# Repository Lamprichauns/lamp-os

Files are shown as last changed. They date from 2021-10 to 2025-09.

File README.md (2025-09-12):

# LampOS

A platform for retrofitting traditional desk lamps with programmable LED controllers to build unique lighted art structures. Using standardized and user friendly hardware based on the ubiquitous ESP32, Neopixels and common sensors, this project seeks to simplify the job of building curious and surreal LED projects for the community to enjoy.

## Lamp Personality & Behaviours

The vision for the lamps is that they remain mostly still and static, as a contrast to the plethora of sound reactive and blinky light art out there. The brightness of the lamps and the colorful glowing base draws attention to the juxtaposition of an ordinary household object in extraordinary places.

Within this vision there is room for the lamps to have personality, shown through subtle behaviour based on things like time, randomness, sensor data, presence/absence of other lamps, etc.

With these sorts of subtle changes, people may begin to realize things are not as static as they seem, creating a somewhat complex puzzle for people to solve and talk about.

## Selecting a lamp to convert

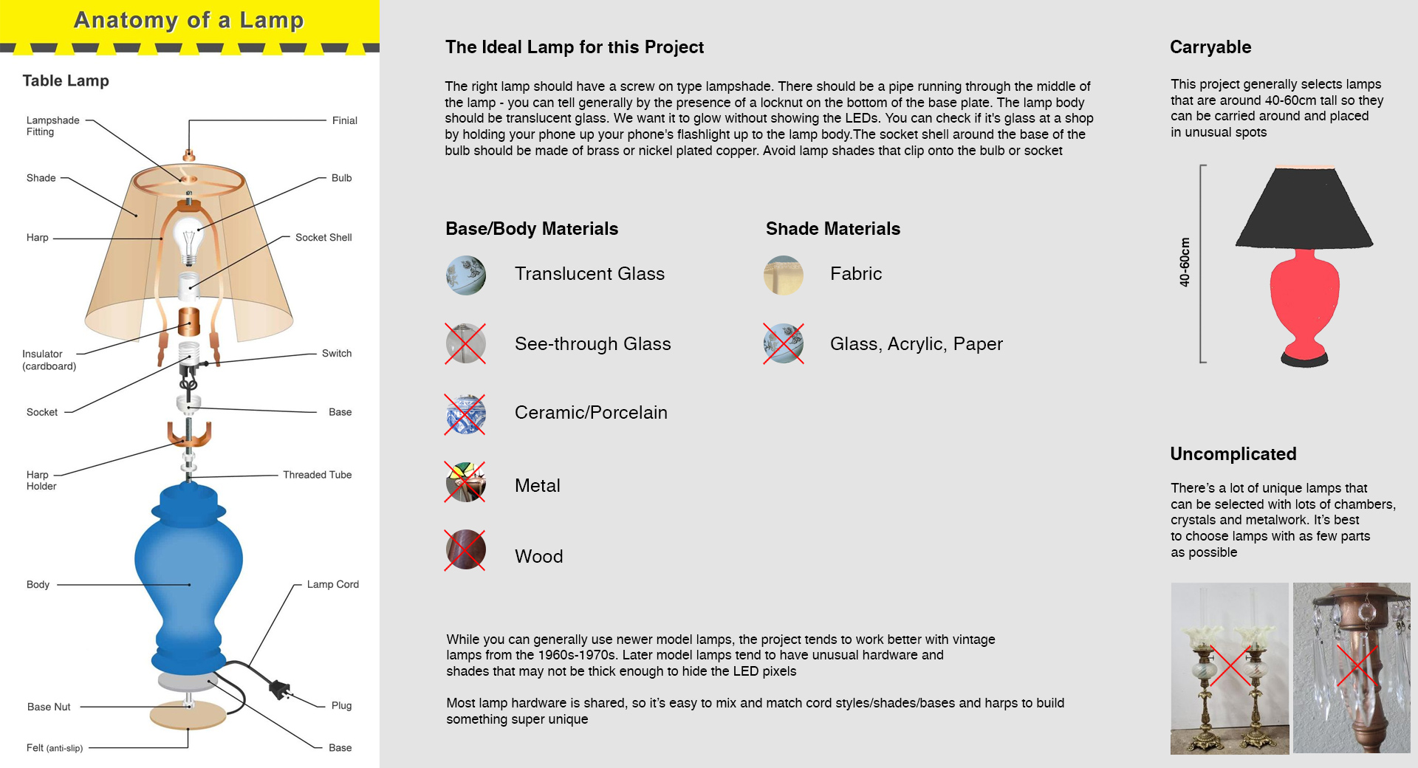
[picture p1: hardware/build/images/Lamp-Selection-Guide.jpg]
Preferred lamp guidelines


## Lamp Hardware Requirements

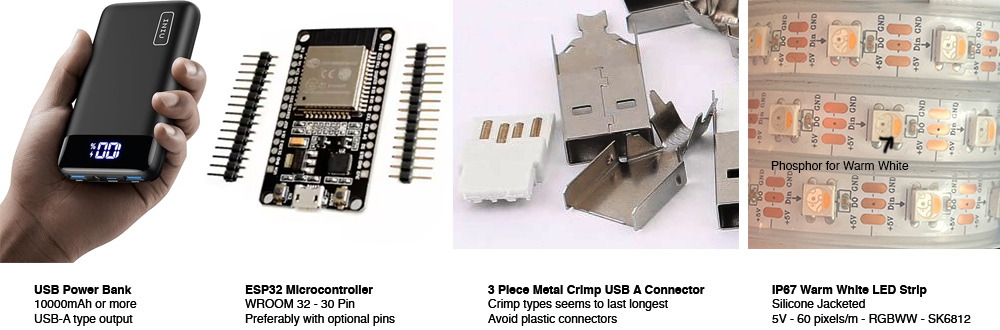
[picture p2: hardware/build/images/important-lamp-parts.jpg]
Main Lamp Components


This software is intended for the ESP32 platform. Our preferred dev board is an ESP32-WROOM32 30 Pin board variant measuring no wider than 28mm with a chip antenna. Unsoldered/unwelded pins are preferred if possible. This space requirement is so the board can fit comfortably into a standard lamp socket. The boards can be had easily from Amazon and AliExpress for $5-10. The model we use has this pinout <https://lastminuteengineers.com/esp32-pinout-reference/>

The USB connector is a USB type A metal shell crimp on connector. These tend to be the most robust.

By default, a lamp will use about 80 LEDs. The limiting factor at the moment is current draw. generally over 100 LEDs you may have stability issues with a conventional USB source. We recommend purchasing LEDs strips with the following specs:

- Around 2m in length
- SK6812 chipset
- IP67 waterproof
- 5VDC
- RGBWW (warm white) LED Strips
- Spacing of 60 LEDs/m

A 10000mAh battery pack with USB will run this device portably for around 7 hours

You'll also need some basic workshop tools, heat shrink, wire connectors, a soldering iron and a way to print the plastic bulb

There's a handy [build guide with images here](hardware/build/README.md)

## Lamp OS

More details about Lamp OS and other supporting tools can be found in the [software](software/) folder

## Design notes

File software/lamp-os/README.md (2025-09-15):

# Lamp OS

---
This is the main software aboard the lamps. It's a small LED driver focused on slow animations and social behaviors

## Contributing

This project runs on pioarduino, a VS Code plugin for all platforms. Pioarduino can be found in the VS Code marketplace

## Prerequisites

You'll need the following software packages

* <https://www.python.org/downloads/> (At least version 3.10)
* Python 3.10+ added to your path
* <https://code.visualstudio.com/>
* pioarduino (accessed from VS Code's extensions tab)

## Opening the project

 Clone this branch to a local folder. Find the folder in the Pioarduino tab on the sidebar of VS Code

## Setting up your editor

We're using Google's code style for this application. All lamp specific code will be added to a flat `lamp` namespace.

You can auto format your code by changing the Vscode settings (ctrl + shift + p > Open user settings (json)):

```json
    "cSpell.diagnosticLevel": "Hint",
    "editor.formatOnSave": true,
    "editor.formatOnSaveMode": "file",
    "C_Cpp.clang_format_fallbackStyle": "{ BasedOnStyle: Google, IndentWidth: 2, ColumnLimit: 0}"
```

## Flashing

 Currently the flash process is a few steps:

 If you've got a completely new board, it's prudent to run erase flash to completely clear your device:

* Pioarduino in the VSCode sidebar -> Project Tasks -> Platform -> Erase Flash

To push the web app in the data dir, you can run

* Pioarduino in the VSCode sidebar -> Project Tasks -> Platform -> build filesystem image
* Pioarduino in the VSCode sidebar -> Project Tasks -> Platform -> upload filesystem image

To upload the factory firmware image:

* Pioarduino in the VSCode sidebar -> Project Tasks -> General -> upload

 Note that depending on the board, you may need to hold the boot button in order to flash the board.

## Updating the web app for development

Plug your lamp board into a usb port

In VSCode, navigate to `Pioarduino > Quick Access > Miscellaneous > pioarduino core CLI`

This will bring up a window in the correct environment to upload

```bash
cd ../lamp-ui
npm ci
npm run build:upload
```

This process will build a new .spiffs partition and replace it onboard your esp32.

## Distribution

While you can program boards through the IDE, Lamp OS intends to be deployed on the web so anyone can format and maintain their own firmware

## OTA Updating

Join your lamp's wifi and navigate to <http://lamp.local/update> and update the following two files in pairs:

Lamp's main firmware:

* file: firmware.bin
* OTA Mode: Firmware

Lamp's mobile UI:

* file: spiffs.bin
* OTA Mode: LittleFS/Spiffs

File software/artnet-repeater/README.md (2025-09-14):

# ArtNet Repeater

---
This is an unstable branch for development of an artnet repeater to control multiple lamps from one unicast ArtNet address with support for a single universe. This project uses wifi on an Seeed Xiao ESP32C6 board with a remote antenna. There will be more packet loss on chip antennas and more noticeable lag in animations as a result

## Contributing

This project runs on pioarduino, a VS Code plugin for all platforms. Pioarduino can be found in the VS Code marketplace.

## Prerequisites

You'll need the following software packages

* <https://www.python.org/downloads/> (At least version 3.10)
* Python 3.10+ added to your path
* <https://code.visualstudio.com/>
* pioarduino (accessed from VS Code's extensions tab)

## Opening the project

 Clone this branch to a local folder. Find the folder in the Pioarduino tab on the sidebar of VS Code

## Setting up your editor

We're using google's code style for this application

You can auto format your code by changing the vscode settings (ctrl + shift + p > Open user settings (json)):

```json
    "cSpell.diagnosticLevel": "Hint",
    "editor.formatOnSave": true,
    "editor.formatOnSaveMode": "file",
    "C_Cpp.vcFormat.newLine.beforeOpenBrace.namespace": "sameLine",
    "C_Cpp.vcFormat.newLine.beforeOpenBrace.type": "sameLine",
    "C_Cpp.vcFormat.newLine.scopeBracesOnSeparateLines": false,
    "C_Cpp.vcFormat.newLine.beforeOpenBrace.block": "sameLine",
    "C_Cpp.vcFormat.newLine.beforeOpenBrace.function": "sameLine",
    "C_Cpp.clang_format_fallbackStyle": "{ BasedOnStyle: Google, IndentWidth: 2 }"
```

## Project Setup

Copy the file `secrets_sample.hpp` to `secrets.hpp` and add any WiFi and stage name credentials you want. Otherwise leave it blank

Some restrictions:

* stage name must be under 12 chars and lower case
* wifi ssid and password must be under 24 chars combined

## Flashing

Find and run the following task once Pioarduino has finished setup:

* Pioarduino in the VSCode sidebar -> project tasks -> general -> upload

 Note that depending on the board, you may need to hold the boot button in order to flash the board.

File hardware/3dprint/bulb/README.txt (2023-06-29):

3d printed bulbs are designed to snap onto the original brass sockets that come
with each lamp. LEDs are wrapped around the upper part of the bulb and secured
with silicone and clear gorilla tape. The 3 LED wires use the hole in the
housing and should be sealed with silicone to prevent water from getting in

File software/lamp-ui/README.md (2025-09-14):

# Lamp OS Color Picker

A mobile-first Vue.js color picker component with hexww (hex + warm white) support. Built with Vue 3, TypeScript, and Vitest.

## Features

- **Hexww Support**: Supports 8-digit hex values with warm white component (e.g., `#FF0000FF`)
- **Mobile-First Design**: Responsive design that works great on mobile devices
- **Interactive Dialog**: Click-to-open color picker with sliders for RGBA and warm white
- **Real-time Updates**: Changes to sliders update the hex value in real-time
- **Background Shading**: Modal dialog with clickable overlay to close
- **TypeScript Support**: Fully typed with TypeScript
- **Comprehensive Testing**: Unit tests with Vitest

## Color Format

The color picker supports the hexww format:

- **Standard Hex**: 6-digit hex values (e.g., `#FF0000`)
- **Hexww**: 8-digit hex values with warm white component (e.g., `#FF0000FF`)

The format is: `#RRGGBBWW` where:

- `RR` = Red component (00-FF)
- `GG` = Green component (00-FF)
- `BB` = Blue component (00-FF)
- `WW` = Warm White component (00-FF)

## Installation

```bash
# Clone the repository
git clone <repository-url>
cd software/lamp-ui

# Install dependencies
npm ci

# Start development server
npm run dev

# Run tests
npm run test:unit

# Build for production
npm run build
```

## Usage

### Basic Usage

```vue
<template>
  <ColorPicker v-model="selectedColor" />
</template>

<script setup>
import { ref } from 'vue'
import ColorPicker from '@/components/ColorPicker.vue'

const selectedColor = ref('#FF0000FF')
</script>
```

### Component Props

| Prop | Type | Default | Description |
| --- | --- | --- | --- |
| `modelValue` | `string` | `''` | The hexww color value |

### Component Events

| Event | Payload  | Description |
| --- | --- | --- |
| `update:modelValue` | `string` | Emitted when the color value changes |

## Development

### Project Structure

```
src/
├── components/
│   ├── ColorPicker.vue          # Main color picker component
│   └── __tests__/
│       └── ColorPicker.test.ts  # Component tests
├── views/
│   └── HomeView.vue             # Demo page
├── App.vue                      # Root component
└── main.ts                      # Application entry point
```

### Running Tests

```bash
# Run all tests
npm run test:unit

# Run tests in watch mode
npm run test:unit -- --watch
```

### Building

```bash
# Build for production
npm run build

# Preview production build
npm run preview
```

### Uploading to your board

Plug your lamp board into a usb port

In VSCode, from the `lamp-os` project, navigate to `Pioarduino > Quick Access > Miscellaneous > pioarduino core CLI`

This will bring up a window in the correct environment to upload

```bash
cd ../lamp-ui
npm ci
npm run build:upload
```

This process will build a new .spiffs partition and replace it onboard your esp32.

## Features in Detail

### Color Picker Dialog

- **Color Preview**: Large preview of the selected color
- **Hex Input**: Direct hex value input with validation
- **RGBA Sliders**: Individual sliders for red, green, blue, and warm white
- **Real-time Updates**: All changes update the hex value immediately
- **Click Outside to Close**: Click the overlay or X button to close

### Mobile Responsiveness

- Optimized for touch interactions
- Responsive layout that adapts to screen size
- Touch-friendly sliders and buttons
- Proper viewport handling

### Accessibility

- Proper ARIA labels
- Keyboard navigation support
- Focus management
- Screen reader friendly

## Example Colors

The demo page includes several example colors:

- **Pure Red**: `#FF0000FF`
- **Pure Green**: `#00FF00FF`
- **Pure Blue**: `#0000FFFF`
- **Warm White**: `#000000FF`
- **Purple**: `#800080FF`
- **Orange**: `#FF8000FF`
- **Cyan**: `#00FFFFFF`
- **Magenta**: `#FF00FFFF`

## Technologies Used

- **Vue 3**: Progressive JavaScript framework
- **TypeScript**: Type-safe JavaScript
- **Vite**: Fast build tool and dev server
- **Vitest**: Unit testing framework
- **Vue Router**: Client-side routing
- **Pinia**: State management
- **ESLint**: Code linting
- **Prettier**: Code formatting

## Browser Support

- Chrome (latest)
- Firefox (latest)
- Safari (latest)
- Edge (latest)
- Mobile browsers (iOS Safari, Chrome Mobile)

## License

MIT License - see LICENSE file for details.

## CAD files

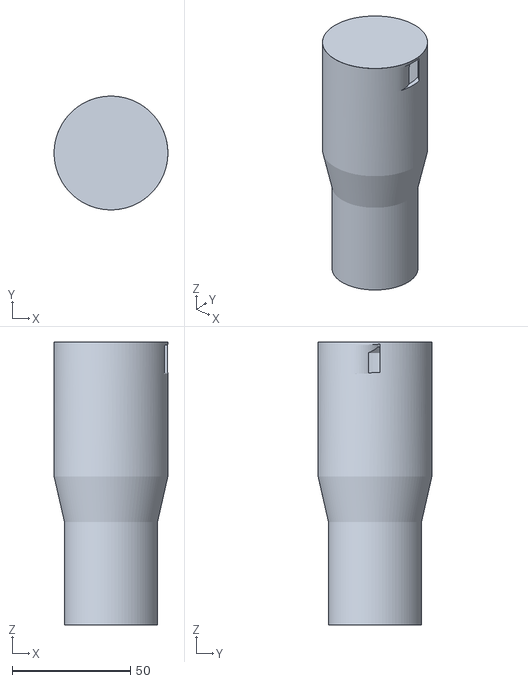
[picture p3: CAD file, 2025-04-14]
hardware/3dprint/bulb/bulb-with-guides.stl
48.2 x 48.1 x 119.8

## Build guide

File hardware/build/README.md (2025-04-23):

# Lamp Build Guide

As part of the process for making a lamp using Lamp OS, you'll need to convert the lamp to use a DC power source and add LEDs to the shade and base. This guide shows how we usually convert a lamp as an illustrated guide

## Prerequisites

To begin your build, you'll need a number of parts and tools ready to go

### Lamp Parts

More technical details of the parts you'll need to purchase can be found on the [main readme](../../README.md)

- A working lamp and shade
- USB Type A plug
- Some 4in cable ties
- An ESP32 board programmed with Lamp OS
- about 1.5m of 5V Neopixel style LED strip
- Some 24ga hookup wire in blue, red, black and yellow
- 3D printed bulb (optional)
- a pack of 24ga marettes (optional)
- a pack of lamp hardware (extra nuts/bolts/washers)
- a multimeter
- heat shrink tubing: 2, 3 and 10mm diameter
- a USB power bank (10000mAh or more)

### Tools

- hand drill and some assorted metal drill sizes
- wire cutters and strippers
- soldering iron
- some locking pliers/Visegrips for removing lamp hardware
- screwdrivers for lamp hardware (small phillips and slot head)
- 3d printer (optional)

## Parts of a Lamp

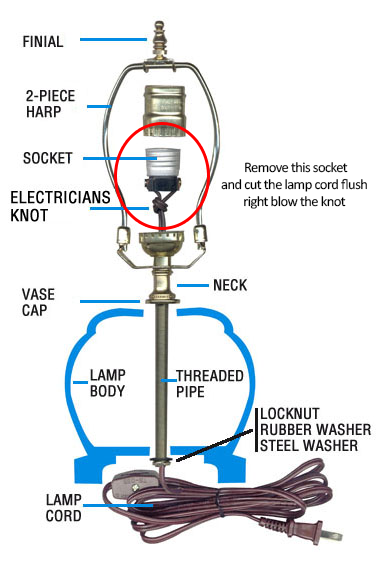
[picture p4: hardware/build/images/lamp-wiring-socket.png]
Basic lamp terminology


## Disassembly

To begin, you'll have to disassemble your lamp. The easiest way I've found to do this:

 1. remove the lampshade and light bulb
 2. unscrew the locking screw just below the bulb socket if it's there
 3. grab the base of the lamp and the socket and gently rotate them to loosen the entire internal assembly.
 4. The socket should completely unscrew from the rest of lamp hardware with enough turns
 5. clip the lamp cord at the socket side (shown in the figure above). Once the lamp cord is cut, you can pull it out of the lamp. It'll be reused in a later step
 6. take all the rest of the hardware apart and take some photos of the order that the parts go together
 7. put all the glass aside in a safe spot until final assembly

## Things to Build Ahead of Time

### Build a 3d printed shade bulb

Cut 35 LEDs from the strip and solder 3 wires - you may need to pull the LED strip out a little:

- black -> gnd
- yellow -> Din
- red -> +5V

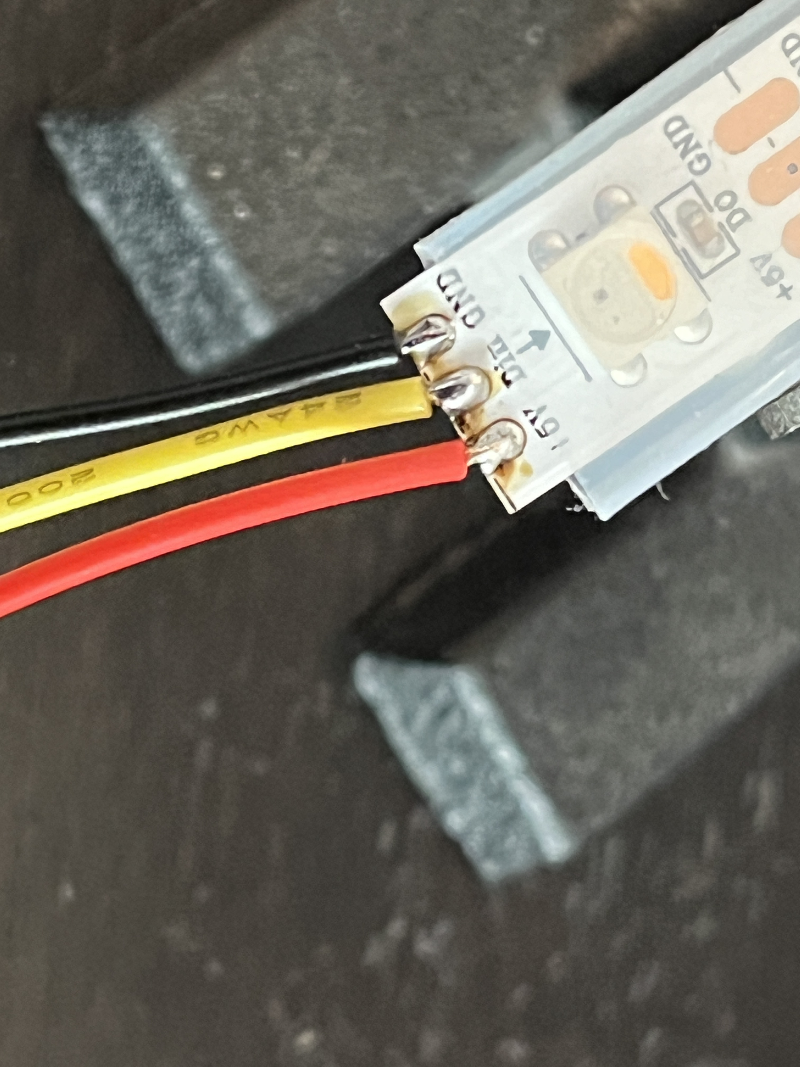
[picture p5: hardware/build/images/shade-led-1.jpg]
Soldering the Shade LEDs


Push the wires through the lower hole and clean up the 3d print so it's square as possible

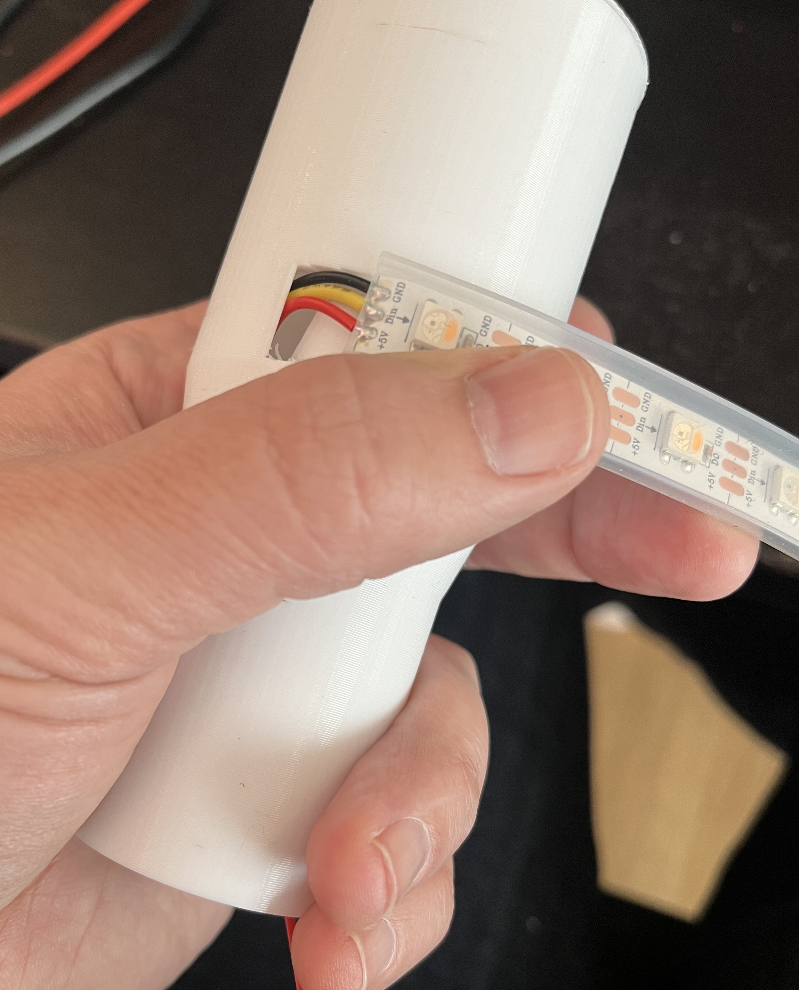
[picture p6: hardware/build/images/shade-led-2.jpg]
Push wires into the bulb


Wrap the LEDs around the bulb and tuck them into the top hole

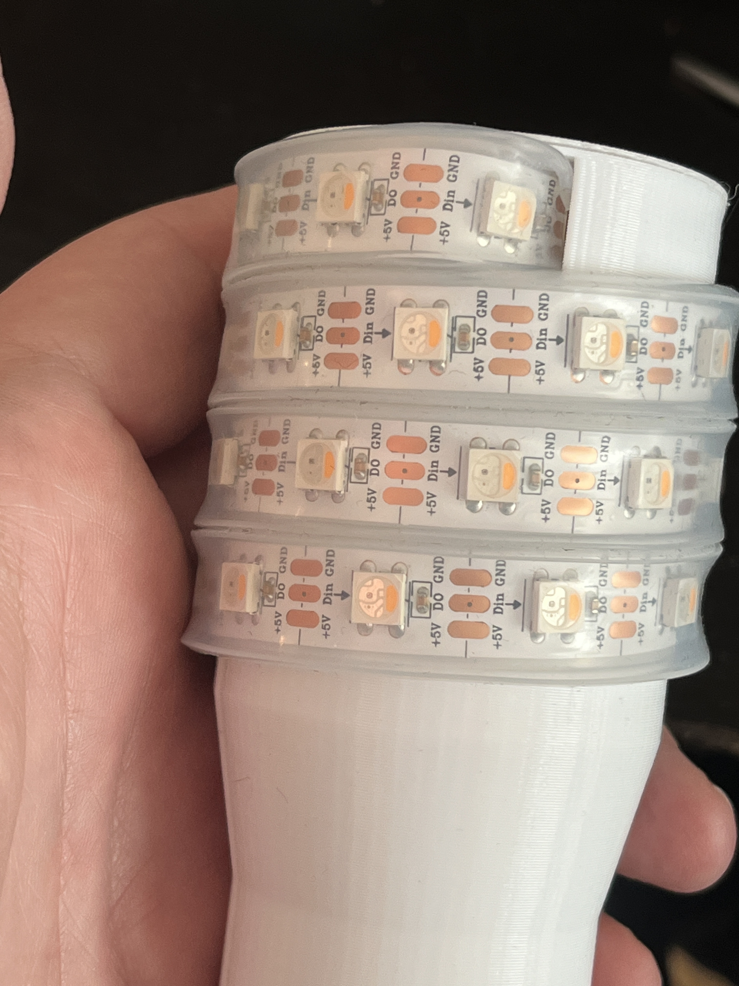
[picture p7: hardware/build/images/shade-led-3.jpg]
The bulb should hold the LEDs in place


Once the LEDs are in place, wrap them in clear tape to fasten them for good

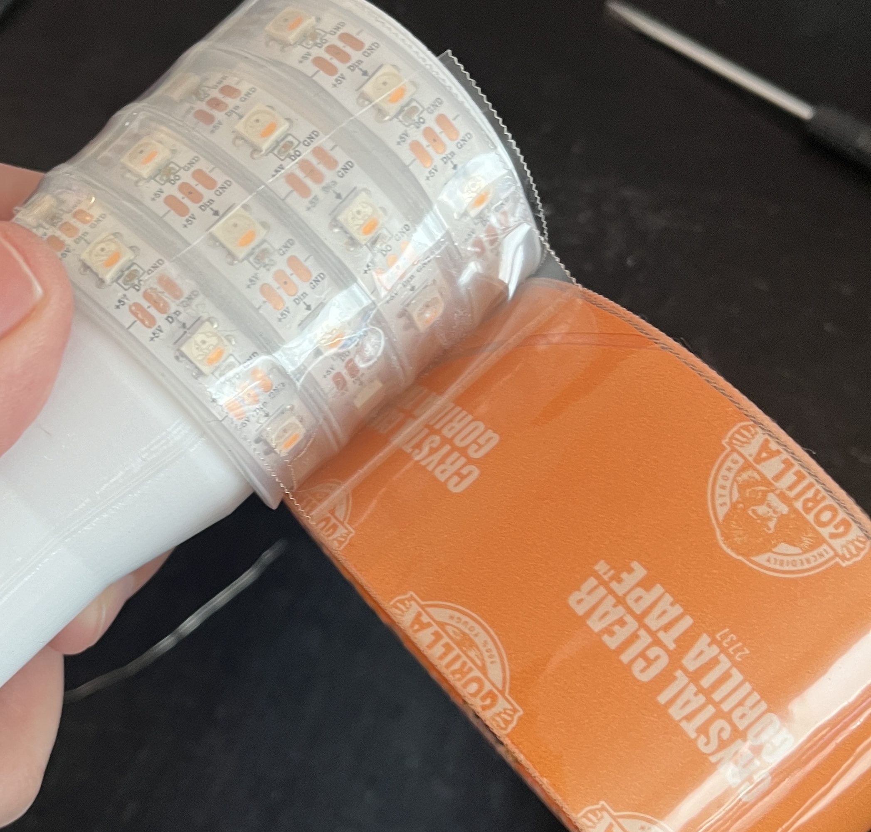
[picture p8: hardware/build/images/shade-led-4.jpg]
Wrap the LEDs with a couple layers of tape


### Build the PCB

Cut 4 wires around 6" each

- black -> GND
- red -> +5v/VIN
- yellow -> D12
- blue -> D14

You can zip tie these wires from any of the board's screw holes next to the D32 or EN pins.

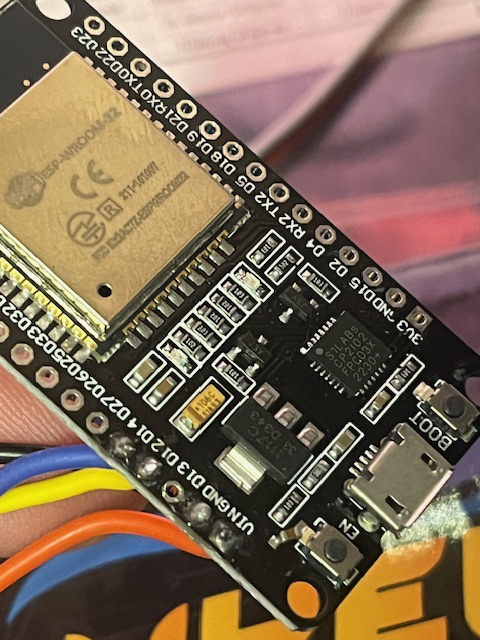
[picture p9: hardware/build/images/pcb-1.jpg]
PCB wiring

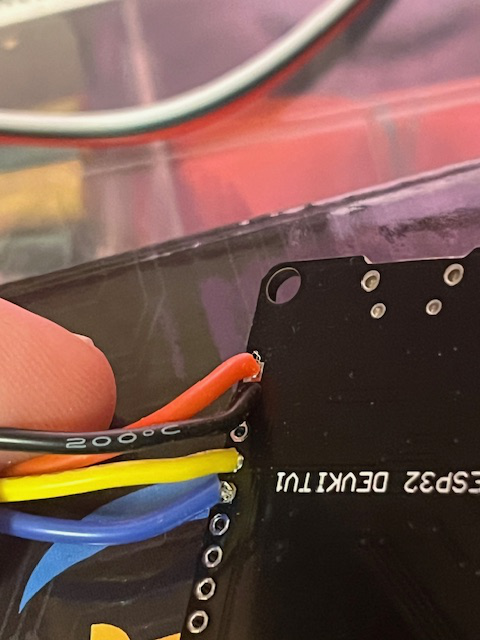
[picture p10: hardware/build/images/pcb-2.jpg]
PCB Wiring


## Assembly

Now the lamp is in pieces, we can begin converting it. The goal of the lamp conversion is to wire it up like this

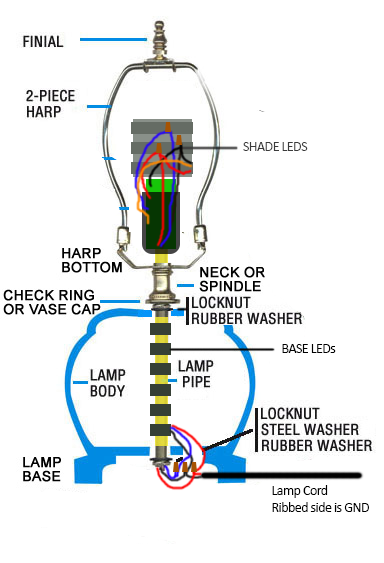
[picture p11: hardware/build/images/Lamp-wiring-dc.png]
Assembly plan


### Build Steps

Begin by drilling a few holes in the base. These holes should be as close to the lower locknut as possible.

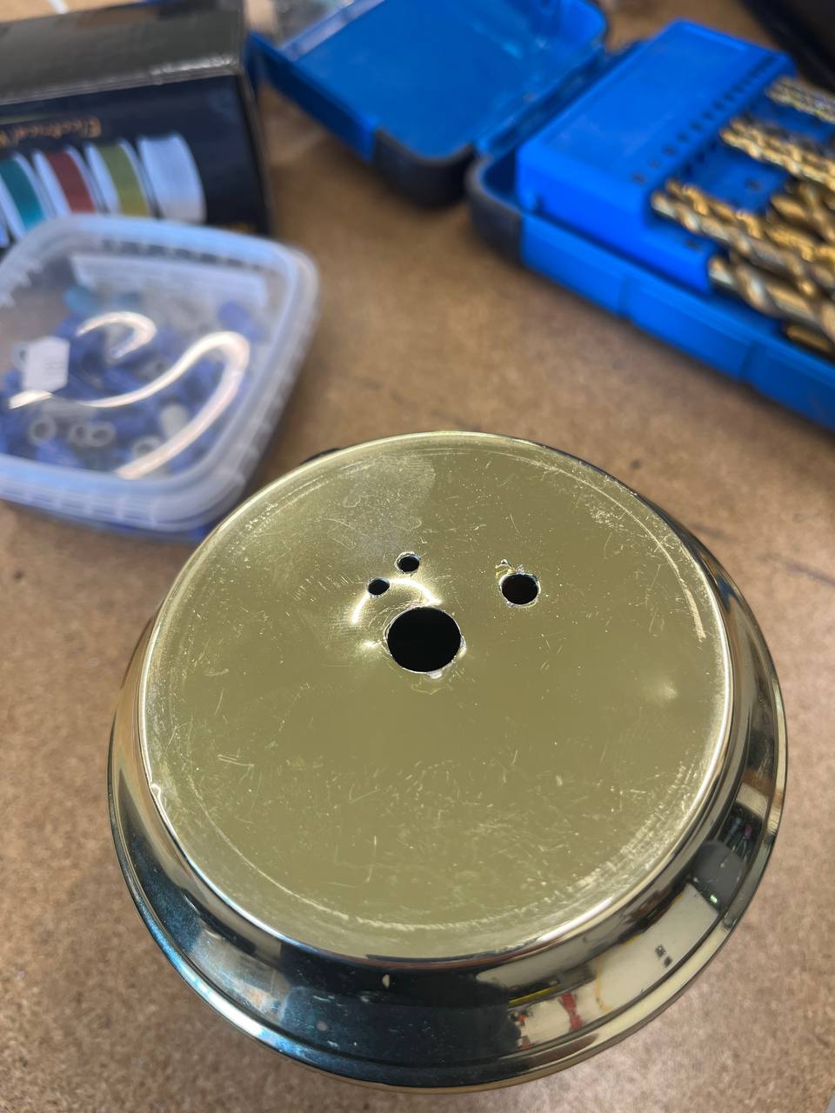
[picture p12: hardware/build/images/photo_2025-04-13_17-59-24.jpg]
Drilling the lamp base


Place a zip tie through the two smaller holes

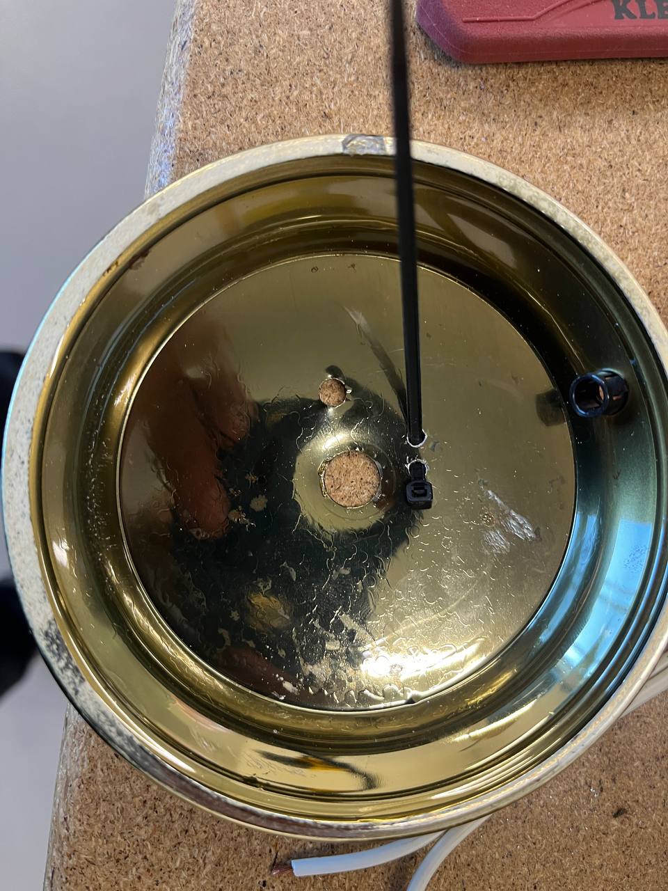
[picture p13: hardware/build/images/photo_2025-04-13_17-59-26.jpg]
Cord zip tie


Install the lamp pipe into the lamp base and install a top and bottom nut and bottom lock washer to secure the pipe in place. You may need to test fit the base glass a few times to ensure the pipe is in the right position

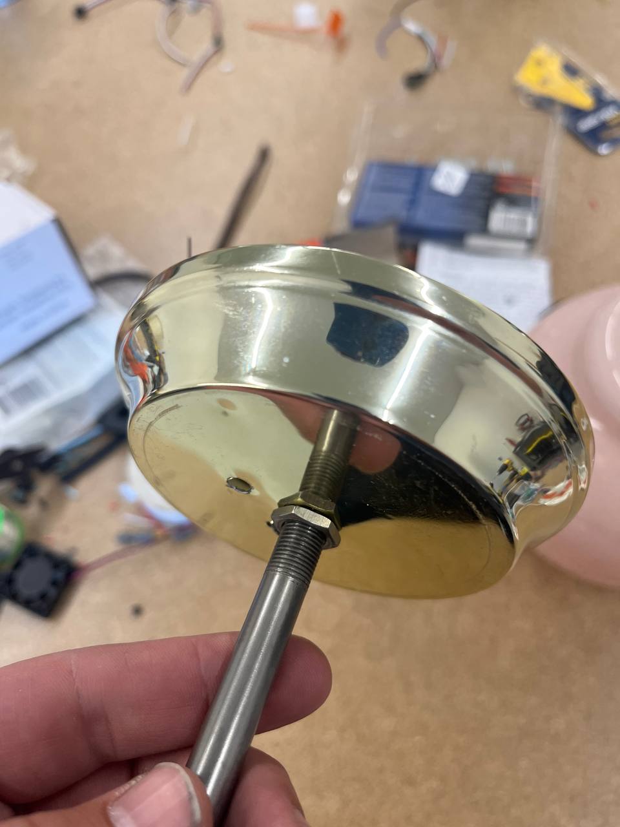
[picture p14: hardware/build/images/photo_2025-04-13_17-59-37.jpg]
Install the lamp pipe


Cut and remove the lamp cord from the socket

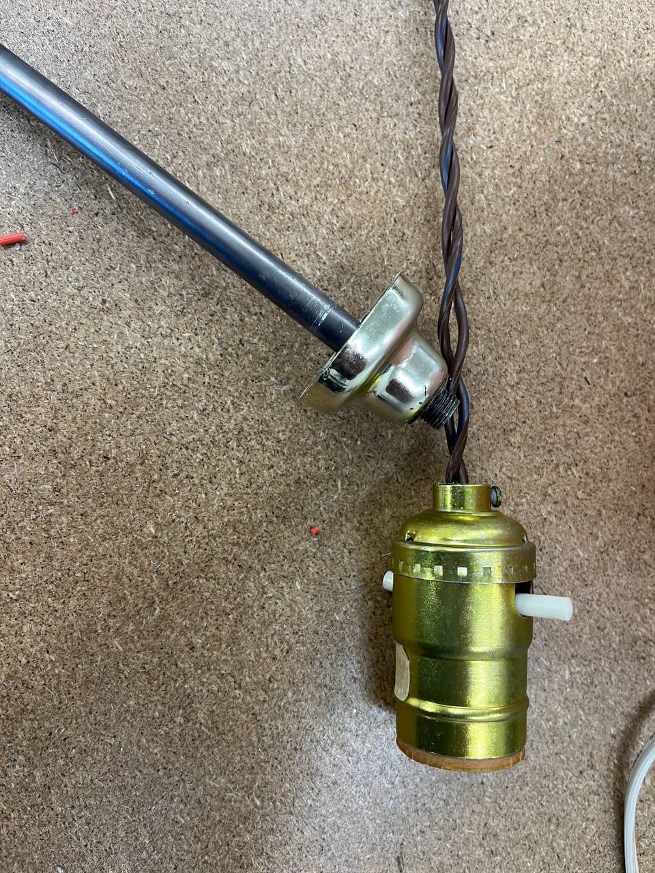
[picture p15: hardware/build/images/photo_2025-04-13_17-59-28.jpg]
Cut the lamp cord to prepare to convert it to USB


Strip the cable and solder it to the USB connector. The ribbed or striped side of the cable should be ground. Keep the solder as low profile as possible so it doesn't touch the metal on the top side of the connector. Close the connector by clipping in the top metal can part.

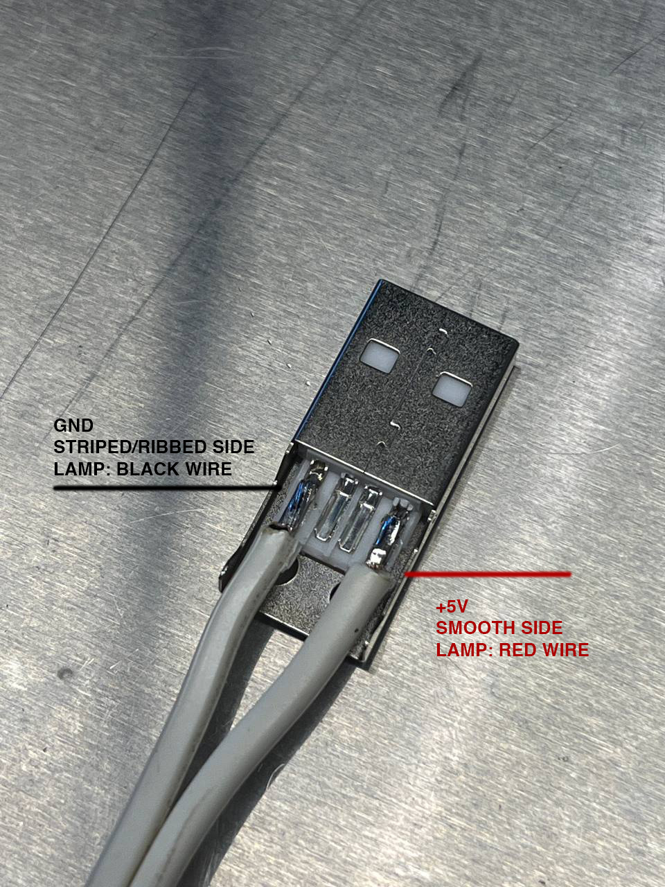
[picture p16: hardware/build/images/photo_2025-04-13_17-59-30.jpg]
Solder the USB connector


Double check your work on soldering the connector with a multimeter. Plug the connector into the battery. Connect the black lead to the ribbed/striped side of the lamp cord and the red lead to the other. In DC voltage mode, make sure 2-5V is coming out of the connector and in the right polarity

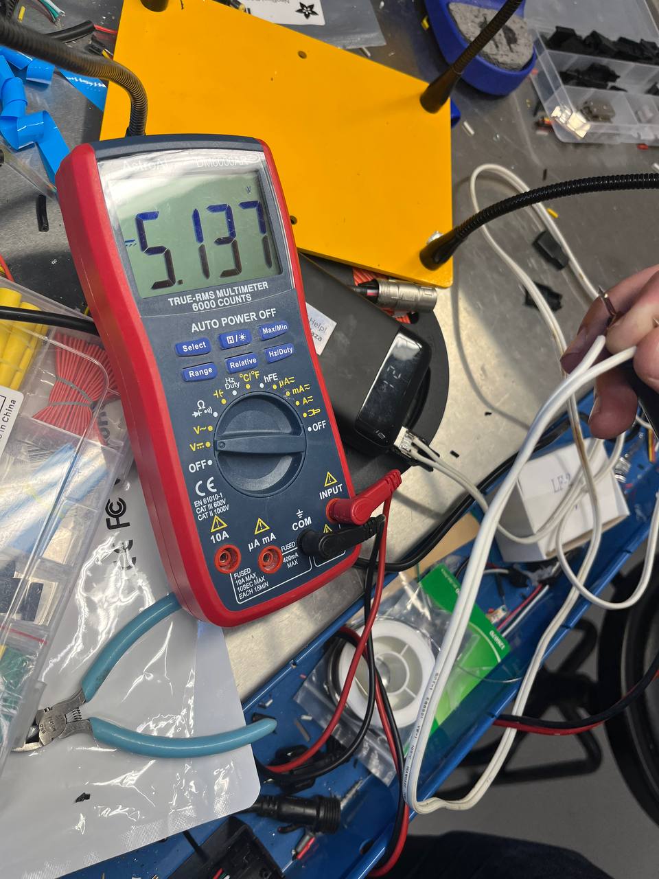
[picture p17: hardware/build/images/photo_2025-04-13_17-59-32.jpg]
Check for 2-5V on the other end of the lamp cord


Crimp the connector firmly to the wire using locking pliers or a crimp tool. Retest the connector once assembled and crimped. Apply heat shrink tubing (10mm diameter) up to about the midpoint of the usb connector and heat til it's tight. The lamp cord is now complete

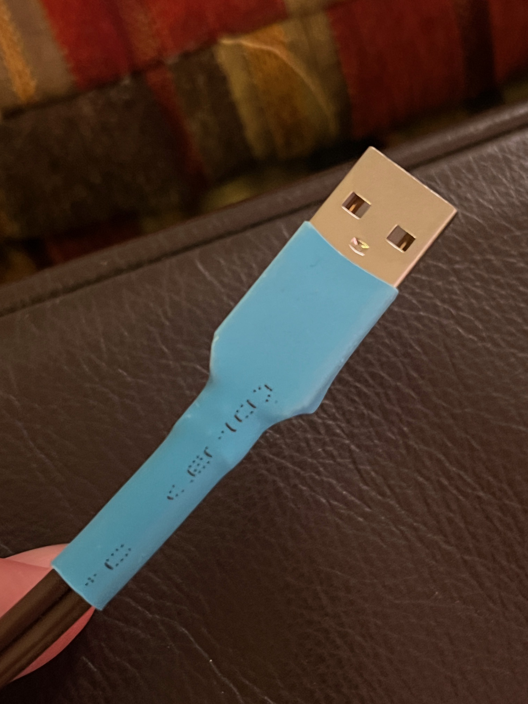
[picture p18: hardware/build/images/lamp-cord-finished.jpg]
finishing touches for the lamp plug


On the base LED strip, solder 3 wires:

- black -> gnd
- blue -> Din
- red -> +5V

And wrap it around the lamp pipe to the top of the base glass. It's generally about 30-40 LEDs

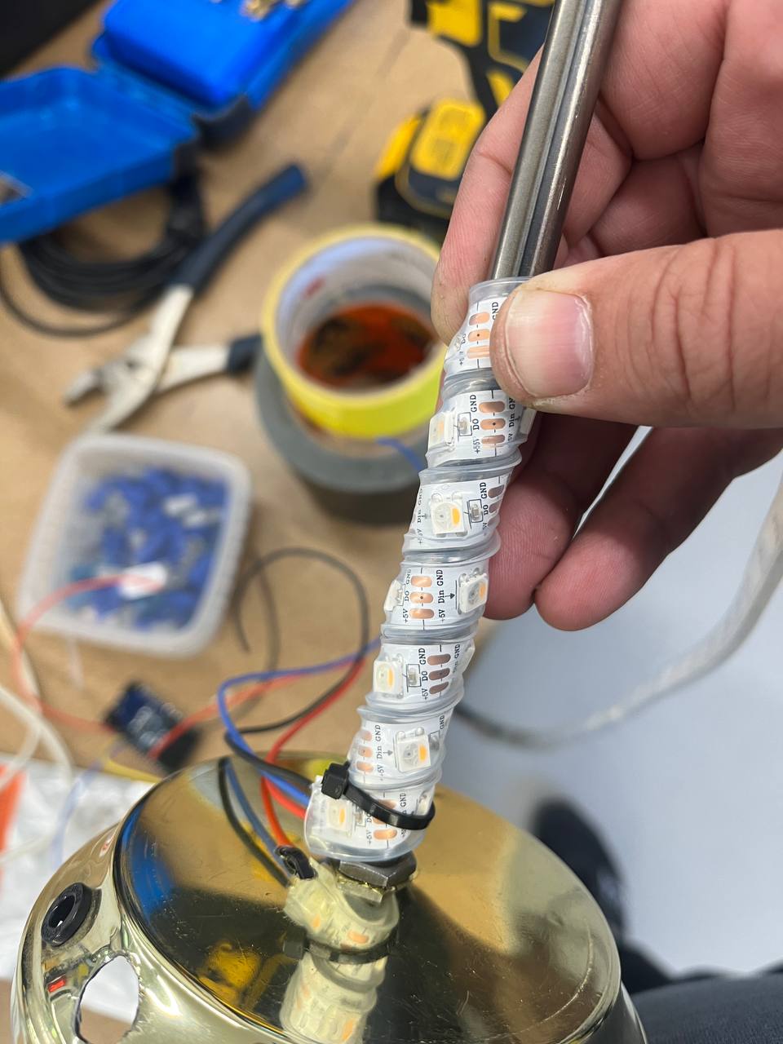
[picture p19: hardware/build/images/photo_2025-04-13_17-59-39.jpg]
Wrap the LEDs around the pipe


Tie off the base LEDs with a couple of wire ties

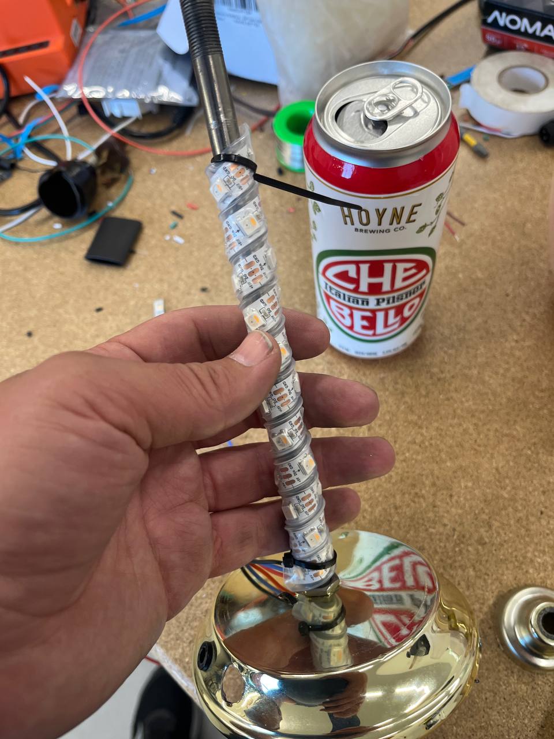
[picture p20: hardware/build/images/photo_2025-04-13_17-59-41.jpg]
More wire ties


We can now begin putting the lamp glass and socket back together. Cut another 3 red, black and blue wires to feed down from the bottom of the socket down to the bottom of the base

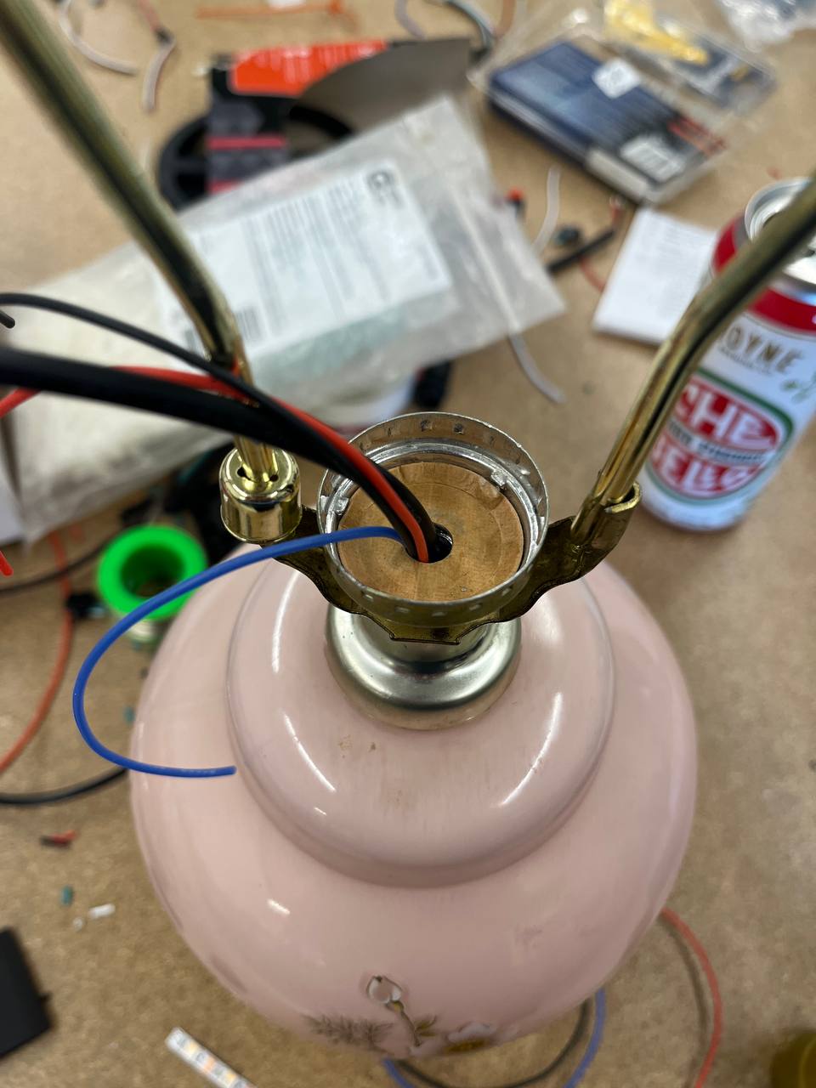
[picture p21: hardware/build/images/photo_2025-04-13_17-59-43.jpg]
Data and power routed back to the base


Put the top of the socket back into place and place the lamp PCB into the socket

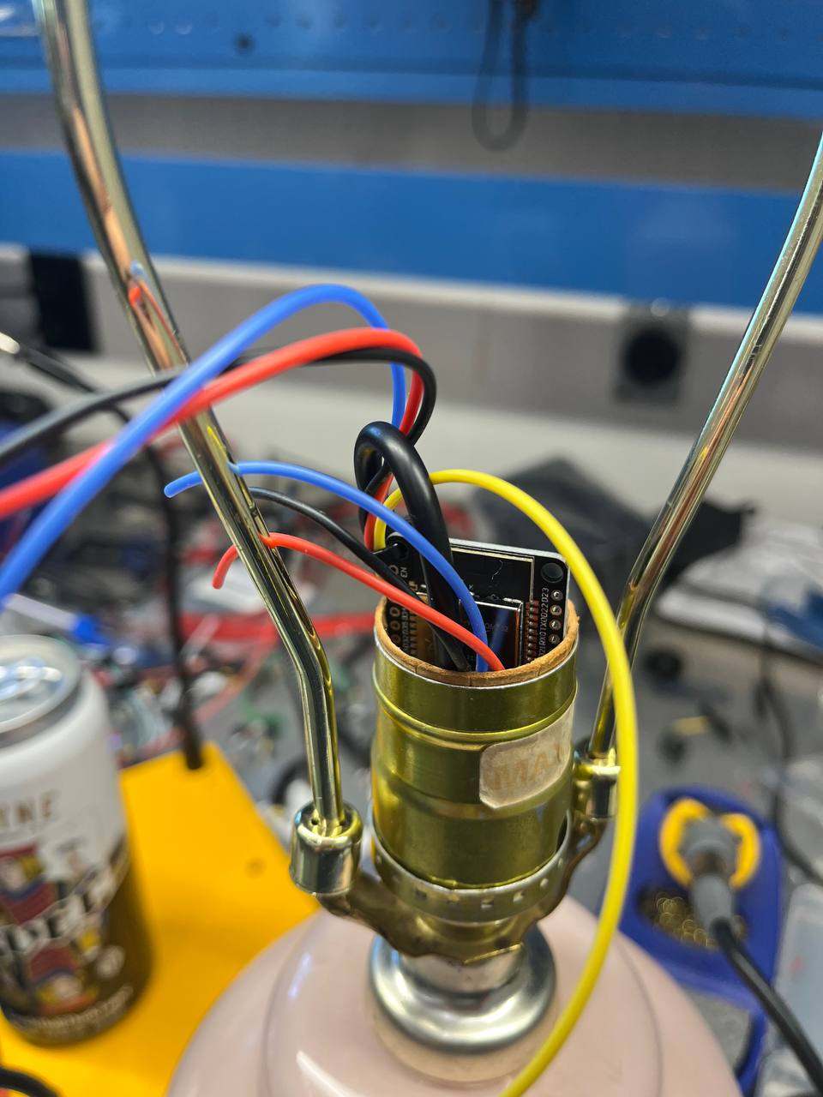
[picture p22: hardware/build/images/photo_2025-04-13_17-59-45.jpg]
Socket PCB wiring


Use marettes to connect all the like colored wires together

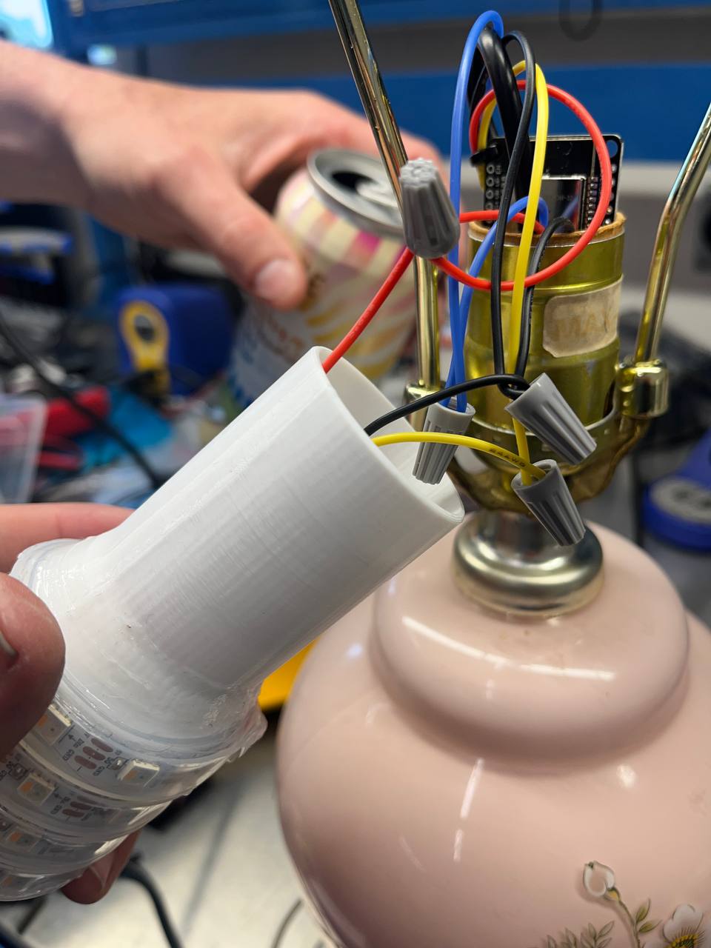
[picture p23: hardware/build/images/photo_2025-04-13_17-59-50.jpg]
Strip and connect all the wires


Once all the connections are made, clip the bulb onto the socket by pushing all the wires into the 3d printed bulb and then pushing down until it clicks into place. If you don't have a 3d printer, you can wrap the LEDs around the harp instead

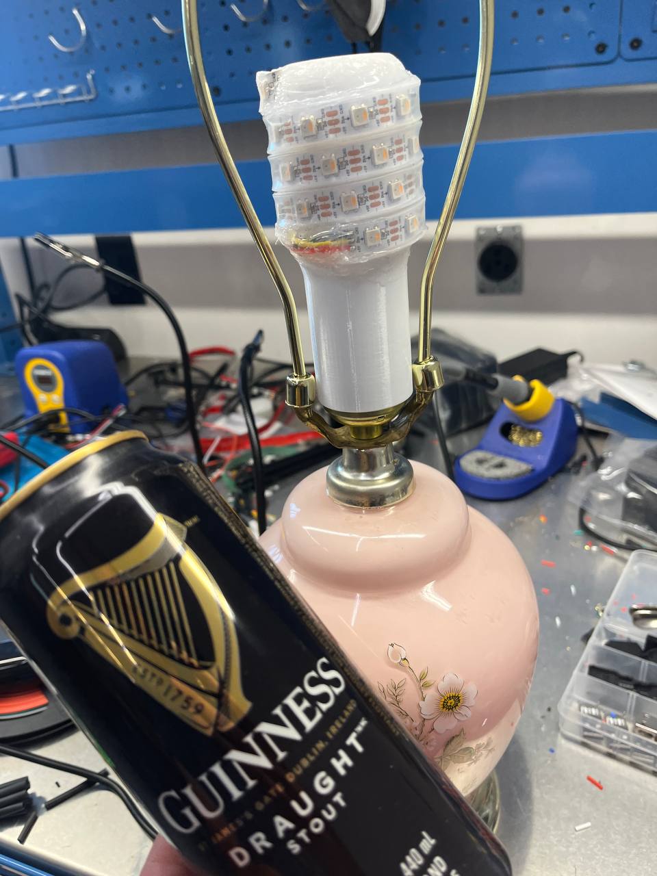
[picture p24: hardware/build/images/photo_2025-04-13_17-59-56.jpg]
Clip on the 3d printed bulb


Now to wire the base. Connect the striped or ridged lamp cord to the black wire. The red to the other lamp cord. Also add the red wire and black wires from the base LEDs and use a marette or solder/heatshrink to connect them all. the blue and blue wire will connect in the same way. Plug in the lamp and make sure it turns on. If it works, then strap them all to the base using the wire tie placed earlier

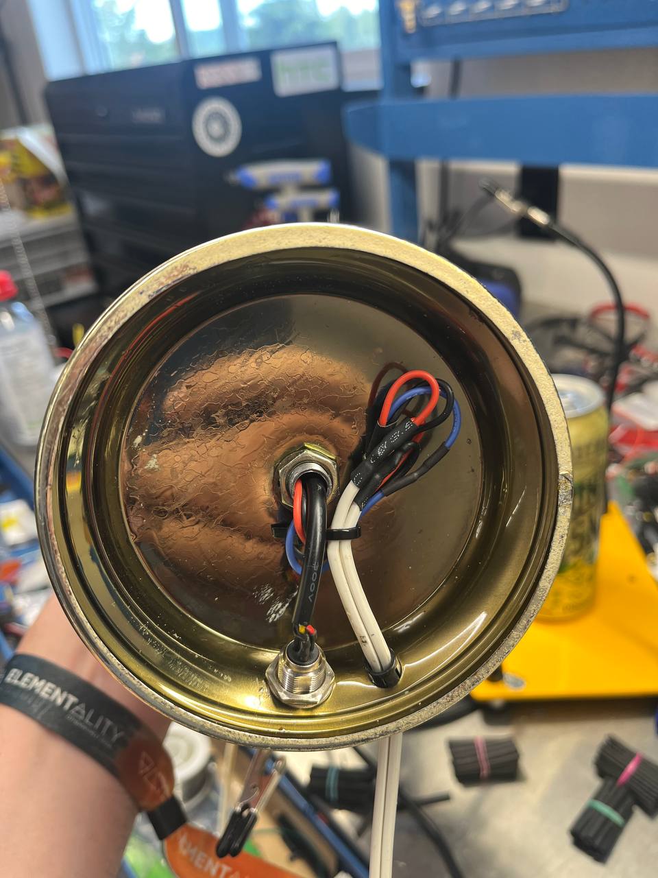
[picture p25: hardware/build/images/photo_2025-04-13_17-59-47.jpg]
Base wiring


> Note: this build includes DMX wiring, the large black cable, which is based on an optional prototype

Add the lampshade and plug the lamp in! With any luck, it'll spin up with the built in colors. From here, you can update your lamp by finding `lamp-configurable` in your wifi list and visiting <http://192.168.4.1> from any web browser to configure the lamp's name and colors.

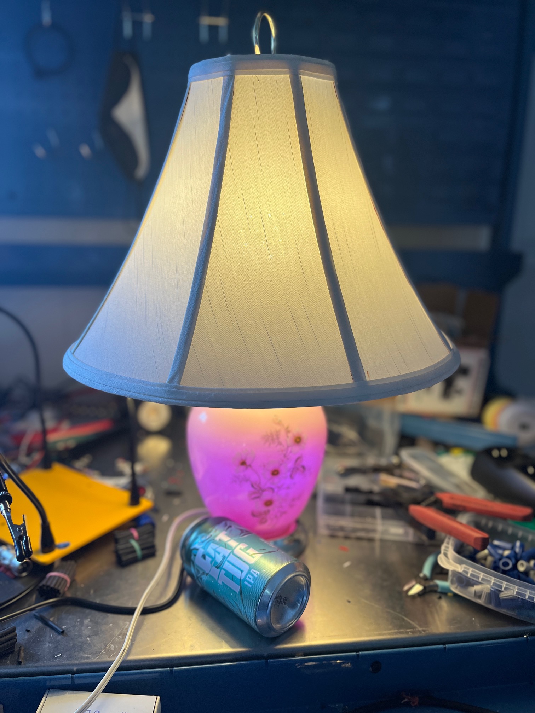
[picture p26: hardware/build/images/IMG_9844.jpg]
Finished lamp


This ends the tutorial for the basic build for the lamps

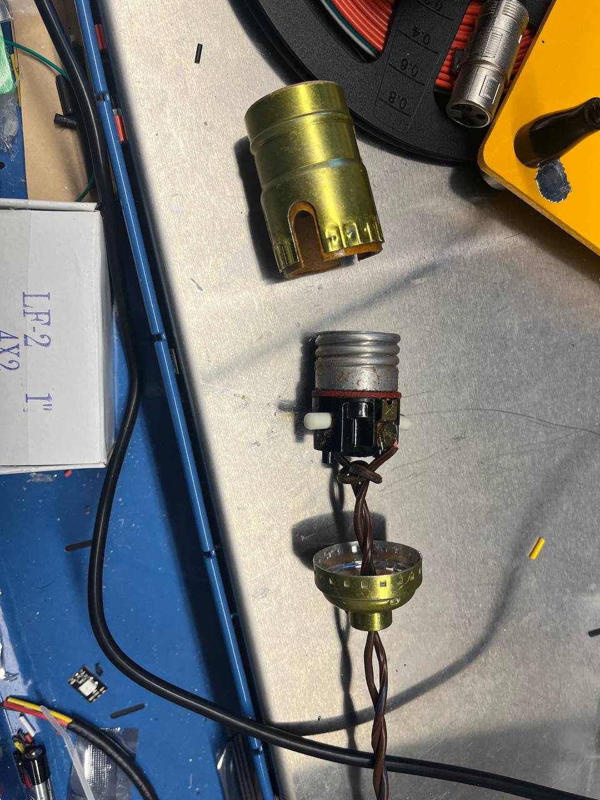
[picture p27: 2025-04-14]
hardware/build/images/photo_2025-04-13_17-59-35.jpg

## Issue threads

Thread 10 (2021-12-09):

FPS-independent transitions

cherrydev, 2021-12-09:
Right now the transitions are specified by a specific number of steps, but depending on the actual 'frame rate' of a lamp (it could be faster for fewer pixels, and slower if there are many) this will mean the amount of time it takes to make a transition would not be consistent. If instead a transition was specified to have a time, it would always be consistent regardless of what the frame-rate is. This could be done by keeping track of the start time of a transition, and then when 'drawing' a frame, you divide the current elapsed time of the transition by the total time of the transition, to give you a number between 0.0-1.0, and then use that to calculate the current value of the color.

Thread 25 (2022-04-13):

[Hardware] ESP32 Module issues

sabjorn, 2022-04-13:
**Note** This only effects the circuit when using ESP32 module (not ESP32 Devkit)
## Problem
ESP32 module is missing several connections on the PCB.

5V signal on EN pin, This should go through a resistor and have a capacitor to ground (as is done on the Devkit circuit).

## Workaround
1) Solder a 10K resistor from 3.3 to En pin.

# Additional Hardware desires:
* level shifter circuit does not seem to be working. It is not needed and should be removed
* esp32 header pin connections need labels
* the side t esp32 dev kits are attached should be clearly labeled

sabjorn, 2022-04-14:
additionally, the level shifter circuit does not seem to be working

Closed 2023-06-27.

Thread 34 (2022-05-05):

Synchronizing LEDs in Lamps

chaffneue, 2022-05-05:
During testing, we've found the multiple behaviors can kick off at once all trying to write pixel values. Without explicit pipelines and methods of organizing animations, this can lead to some fairly jarring, glitchy behaviors. This issue is to look into some control mechanisms for the entire lamp without having to make the code a lot more complicated. Provide an example of a lamp that successfully:

- Fades the lamp in first without interruption
- Runs a long running animation that can be paused and resumed
- Allows for glitch behaviors at any time
- Allows a timed behavior to run on a schedule

chaffneue, 2022-05-31:
The animation system now accounts for the requirements and century lamp can be used as a pathfinding example starting in v0.0.2  https://github.com/Lamprichauns/lamp-os/blob/v0.0.2/src/lamps/century.py

Docs to follow in https://github.com/Lamprichauns/lamp-os/issues/31

Closed 2022-05-31.

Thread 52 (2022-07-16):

[Docs] Digikey ESP32 part link in README.md is broken

SamClayton, 2022-07-16:
404

Closed 2023-06-27.

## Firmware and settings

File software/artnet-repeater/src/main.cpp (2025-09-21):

#include <Arduino.h>
#include <AsyncUDP.h>
#include <NimBLEDevice.h>
#include <WiFi.h>

#include <cstdint>
#include <string>
#include <vector>

#include "./secrets.hpp"
#define ART_NET_PORT 6454
#define MAX_BUFFER_ARTNET 530
#define BLE_MAGIC_NUMBER 42007

#define MIN_UPDATE_TIME 250

AsyncUDP udp;
uint32_t lastUpdate = 0;

void onWiFiEvent(WiFiEvent_t event) {
  Serial.printf("WIFI Event %d\n", event);
};

void setup() {
  Serial.begin(115200);
  Serial.println("Initializing...");
  std::string coordinatorSsid = SECRET_COORDINATOR_SSID;
  std::string coordinatorPassword = SECRET_COORDINATOR_PASSWORD;

  NimBLEDevice::init(SECRET_COORDINATOR_STAGE_NAME);
  uint8_t result = NimBLEDevice::setPower(ESP_PWR_LVL_P9, NimBLETxPowerType::Advertise);
  Serial.printf("Setting bluetooth to +9dB with status code: %d\n", result);

  // Stage coordinators advertise the following packet
  // 2 bytes: coordinator identifier [Manufacturer ID block]
  // 26 bytes: a null terminated ssid and a null terminated password
  // combined password and ssid should not be more than 24 chars
  NimBLEAdvertising* pAdvertising = NimBLEDevice::getAdvertising();
  pAdvertising->setName(SECRET_COORDINATOR_STAGE_NAME);
  pAdvertising->enableScanResponse(true);
  std::vector<unsigned char> data;
  data.reserve(28);
  std::vector<char> magicBytes{char(BLE_MAGIC_NUMBER & 0xff), char((BLE_MAGIC_NUMBER >> 8) & 0xff)};
  data.insert(data.end(), magicBytes.begin(), magicBytes.end());
  std::vector<char> ssidBytes(coordinatorSsid.c_str(), coordinatorSsid.c_str() + coordinatorSsid.size() + 1);
  data.insert(data.end(), ssidBytes.begin(), ssidBytes.end());
  std::vector<char> passwordBytes(coordinatorPassword.c_str(), coordinatorPassword.c_str() + coordinatorPassword.size() + 1);
  data.insert(data.end(), passwordBytes.begin(), passwordBytes.end());
  pAdvertising->setMinInterval(650);
  pAdvertising->setMaxInterval(800);
  pAdvertising->setManufacturerData(data);
  pAdvertising->setConnectableMode(0);
  pAdvertising->start();

  WiFi.mode(WIFI_STA);
  WiFi.setSleep(false);
  WiFi.setAutoReconnect(true);
  WiFi.onEvent(onWiFiEvent);
  WiFi.config(IPAddress(10, 0, 0, 2),
              IPAddress(10, 0, 0, 1),
              IPAddress(255, 255, 255, 0),
              IPAddress(10, 0, 0, 1));
  WiFi.begin(SECRET_COORDINATOR_SSID, SECRET_COORDINATOR_PASSWORD);
  WiFi.setTxPower(WIFI_POWER_8_5dBm);
  udp.listen(ART_NET_PORT);
  udp.onPacket([](AsyncUDPPacket packet) {
    uint32_t packetSize = packet.length();

    if (packetSize == MAX_BUFFER_ARTNET) {
      uint32_t now = millis();

      if (now > lastUpdate + MIN_UPDATE_TIME) {
        lastUpdate = now;
        uint8_t* data = packet.data();
        udp.writeTo(data, MAX_BUFFER_ARTNET, IPAddress(10, 0, 0, 20), ART_NET_PORT, TCPIP_ADAPTER_IF_STA);
        udp.writeTo(data, MAX_BUFFER_ARTNET, IPAddress(10, 0, 0, 21), ART_NET_PORT, TCPIP_ADAPTER_IF_STA);
        udp.writeTo(data, MAX_BUFFER_ARTNET, IPAddress(10, 0, 0, 22), ART_NET_PORT, TCPIP_ADAPTER_IF_STA);
        udp.writeTo(data, MAX_BUFFER_ARTNET, IPAddress(10, 0, 0, 23), ART_NET_PORT, TCPIP_ADAPTER_IF_STA);
        udp.writeTo(data, MAX_BUFFER_ARTNET, IPAddress(10, 0, 0, 24), ART_NET_PORT, TCPIP_ADAPTER_IF_STA);
        udp.writeTo(data, MAX_BUFFER_ARTNET, IPAddress(10, 0, 0, 25), ART_NET_PORT, TCPIP_ADAPTER_IF_STA);
        udp.writeTo(data, MAX_BUFFER_ARTNET, IPAddress(10, 0, 0, 26), ART_NET_PORT, TCPIP_ADAPTER_IF_STA);
        udp.writeTo(data, MAX_BUFFER_ARTNET, IPAddress(10, 0, 0, 27), ART_NET_PORT, TCPIP_ADAPTER_IF_STA);
        udp.writeTo(data, MAX_BUFFER_ARTNET, IPAddress(10, 0, 0, 28), ART_NET_PORT, TCPIP_ADAPTER_IF_STA);
        udp.writeTo(data, MAX_BUFFER_ARTNET, IPAddress(10, 0, 0, 29), ART_NET_PORT, TCPIP_ADAPTER_IF_STA);
        udp.writeTo(data, MAX_BUFFER_ARTNET, IPAddress(10, 0, 0, 30), ART_NET_PORT, TCPIP_ADAPTER_IF_STA);
      }
    }
  });
}

void loop() {}

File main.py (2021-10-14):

from machine import Pin
from machine import Timer
from time import sleep
import network
import re

# Lamp Config

lamp_name   = "womp"
color       = {"base": '#00ff00', "shade": '#ffffff'}

# Signal strength threshold - weaker signal than this doesn't count as "close".
signal_threshold = -90

# todo list:
# - When using RGBwW strips, automatically use the white when the color is set to #ffffff
# - include the configured base and shade colors in the SSID so other lamps can know what colors their friends are
# - make a lamp object for the lamp_network arrays instead of the strings of lamp names, so we can include default colors in that
# - Create hooks from color setting and move this all to base.py, so we can have [lampname].py that just has config and callbacks to handle behaviour for individual lamps

##########################


class Lamp:
    def __init__(self, name, base_color, shade_color):
        self.name = name
        self.base_color = base_color
        self.shade_color = shade_color

def setup():
    global lamp_network, wifi_sta

    lamp_network = {"current": [], "joined": [], "left": []}

    # Init wifi
    wifi_sta = network.WLAN(network.STA_IF)
    wifi_ap  = network.WLAN(network.AP_IF)

    wifi_ap.active(True)
    wifi_sta.active(True)

    # TODO: make this "LampOS-lampname-basecolor-shadecolor"
    ssid = "LampOS-%s" % (lamp_name)
    wifi_ap.config(essid=ssid, password="lamprichauns")

    print("%s is awake!" % (lamp_name))

def scan_networks():
    networks = wifi_sta.scan()
    nearby_lamps = []
    lamp_network["joined"].clear()
    lamp_network["left"].clear()

    print("\nScanning for lamps..")

    for ssid, bssid, channel, rssi, authmode, hidden in networks:
        ssid = ssid.decode("utf-8")

        match = re.search(r'LampOS-(\w+)', ssid)
        if match: print("Match: %s @ %d db" % (match.group(1), rssi))

        # cycle through all the found lamps
        if (match and rssi >= signal_threshold):
            found_lamp = match.group(1)
            nearby_lamps.append(found_lamp)

            # Track who has joined the network
            if not (found_lamp in lamp_network["current"]):
                lamp_network["joined"].append(found_lamp)
                print("A new lamp is nearby: %s, (%d db)" % (match.group(1), rssi))


    # Track who has left the network
    for lamp in lamp_network["current"]:
        if not(lamp in nearby_lamps):
            lamp_network["left"].append(lamp)
            print("A lamp has left: %s" % (lamp))

    # Set current list
    lamp_network["current"] = nearby_lamps.copy()


#def adjust_colors
  # Call callbacks base_color(), shade_color() to determine color, use config if callbacks are not defined.
  # if new color is not the same as last set color, set the new colors

#####

setup()

# Scan for lamps.
# Making this too frequent could also result in unfavourably reactivity if a lamp
# is on the edge and ebbing in and out of "nearness" - and scanning takes extra power!
# Using virtual timer instead of hardware for compatibility with ESP8266.
timer = Timer(-1)
timer.init(period=10000, mode=Timer.PERIODIC, callback=lambda t:scan_networks())

# Loop pretty quickly, so we can do sub-second color changes if we want.
while True:
    # adjust_colors()
    sleep(0.25)

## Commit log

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2021-10-14 should be main.py & fixed code to properly handle leaving
    [main.py]
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2021-10-19 re-org and fixing modules for multiple lamps
    [lamp.py, main.py]
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2021-11-23 uasync io (but not working)
    [lamp.py]
2021-11-27 no more memory issues, but now it is slow because of the time it takes each step to do the math. runs out of memory if storing it and iterating it after.....
    [lamp.py]
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2021-12-16 shifty and glitchy gramp
    [lamp.py]
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2022-02-01 andromeda added as well as a bunch of tweaks, fixes, etc
    [main.py]
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2022-05-01 Adding more compatibility with my RGB LED class. Now accepts 4 tuples. Removed unused reset method and updated dupe fill method. No longer need to pass the lamp instance to the LED strips. You can no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
    [led_strip_6812_rgbww.py]
2022-05-02 Linting pass - found a couple of bugs and added a pylintrc for those who want it
    [lamp.py, led_strip_6812_rgbww.py]
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2022-05-05 reading configs from a json file. will write to them next. removing webrepl to save memory. fixing temperature algo
2022-05-06 First attempt at concurrent animations - a warp coil sort of effect with a white warning light behind it
    [lamp.py]
2022-05-06 generic neopixel class that can take bpp, fade only allows one at a time (drops old), rm global lock, fix gramp
    [lamp.py]
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2022-05-12 remove the web components from century for now. Add back dance reaction in animated behaviour format. some bugfixes to easing, color tools
    [lamp.py]
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2022-06-03 Attenuating the configurable lamp total PWM. New colors for Empress and small fixes.
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2023-06-27 Adding Nite, A dimmer switch for Howl and some animation fixes around pause
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2023-06-29 More cleanup: upgrading esp32 core to remove glitching from animations. removing unused files to save flash space. removing old tasks tooling
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2025-08-23 correcting artnet color alignment
    [wifi.cpp]
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2025-09-03 adding main - fixing gitignore
    [main.cpp]
2025-09-06 updating build. fixing wrong type in bt debug printf
    [bluetooth.cpp]
2025-09-06 adding a merged build artifact. Fixing some lint errors
    [bluetooth.cpp]
2025-09-09 color picker is now using websockets. Lamp will reboot on web ui changes
    [animated_behavior.hpp]
2025-09-09 touching up shade color reset. Adding global driver dimming to make the gamut make more sense
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2025-09-12 fixing double inclusion of knockout behaviors
    [wifi.cpp]
2025-09-12 Adding some runtime safeguards for configs - adjusting shade pixels to ignore configs as we probably won't change them in standard lamps
    [bluetooth.cpp, wifi.cpp]
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2025-09-15 Adding lamp.local mdns entry. fixing cors
    [wifi.cpp]
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2025-09-15 reverting changes to stage mode in the UI. fixing logo embed in the c++ build
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2026-09-12 fix(lamp): saved colors survive the configurator idle timeout
    Two first-boot/color bugs found by bench-instrumenting the draw path.
    Saved colors reverted ~60s after every edit. IdleBehavior (the underlay)
    blanket-writes fb->defaultColors every frame, and the configurator draws
    over it only while not STOPPED. defaultColors was seeded once in
    Lamp::setup and never updated, so once the configurator idle-stopped at
    CONFIGURATOR_WEBSOCKET_TIMEOUT_MS the strip fell back to the colors the
    lamp booted with. config and NVS were always correct, which is why a
    reboot or an app reconnect "fixed" it -- both just restart the
    configurator. refreshDefaultScene() re-seeds the fallback from the saved
    config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
2026-09-12 ci: pin platformio to 6.1.19 so the IDF build keeps SCons 4.8.1
    The 1.2.7 release builds failed on both lamp variants with
    "ModuleNotFoundError: No module named 'SCons.Tool.FortranCommon'". The
    wisp built fine; only the ESP-IDF builder imports that module.
    CI installs SCons twice: the pioarduino platform pins tool-scons@4.40801.0
    (SCons 4.8.1), then PlatformIO Core installs platformio/tool-scons
    @~4.41101.0 (SCons 4.11.1) over it. 4.11.1 dropped FortranCommon, so the
    IDF builder's import fails. An unpinned `platformio>=6.1.17` let CI drift
    onto a Core that demands the newer SCons; local builds kept working because
    ~/.platformio already had 4.40801.0 cached under Core 6.1.19.
    Co-Authored-By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
2026-09-12 fix(webapp): fade to black on web-config save before rebooting
    A web-config Save hard-restarted the lamp (ESP.restart), cutting the LEDs
    to black instantly. The app/BLE save, adoption, and factory-reset paths all
    fade out first via FadeOutBehavior; the pre-app websocket config UI faded
    too. The on-lamp server rewrite dropped it.
    The save path now sets fadeOutRebootRequested so FadeOutBehavior fades to
    black over REBOOT_ANIMATION_FRAMES (~1.9s) and restarts on its last frame,
    matching every other reboot. The browser-left / idle housekeeping reboots
    keep the hard restart (no scene to fade).
    A fallback deadline (rebootNow re-arms s_rebootAtMs +4s and clears the fade
    flag) guarantees the reboo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
2026-09-29 fix(lamp): disable BT modem-sleep at runtime, not build-time
    WiFi already stays awake (setSleep(false), ESP-NOW is unbuffered) on
    the shared radio, so BT modem-sleep saves ~no power but its PHY
    sleep/wake toggle around connection events triggers a libphy RF-calib
    allocation that aborts under heap fragmentation. The BT controller is
    a precompiled blob so a build flag no-ops; esp_bt_sleep_disable() is
    asserted after every controller bring-up, mirroring the WiFi
    re-assert-after-mode-change pattern.
2026-09-29 feat(lamp): persist a crash record across resets, released builds included
    Stable/beta lamps have no LAMP_DEBUG serial and no coredump partition, so a
    crash in the field left nothing behind. RTC_NOINIT memory now carries the
    panic reason, pc, first four backtrace addresses and core (stamped by the
    panic handler) plus 1 Hz samples of the minimum largest free block, minimum
    free heap, roster peak and uptime. On the next boot a panic / watchdog /
    brownout reset (or a captured panic under any reset) bumps a counter and
    writes the record to NVS. The BLE lamp section exposes it as `lastCrash`
    plus this boot's `resetReason`; payload fields only, GATT layout untouched.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
2026-09-30 fix(lamp): harden the slim roster buffers and crash-record sampling
    - LampRoster::getAll falls back to reserving the current count when the
    kCapacity reservation fails, and caps the fill at capacity so push_back
    never reallocates under the mutex.
    - maintainNearbyJson holds a failed build (OOM or heap-skip) to the 1 Hz
    retry instead of retrying every loop tick.
    - ble_control::stop frees the nearby JSON and roster buffer, which tick()
    stops maintaining once the webapp takes the radio.
    - crash_record::tick samples the roster count only inside its 1 Hz gate.
    - networking.md: /api/settings is the persisted config doc, not the lamp
    section; crash_record::boot comment matches its call sit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
2026-10-09 spike(wisp): OSC palette source over SLIP serial and UDP
    Adds WispSourceMode::Osc (3), an OSC 1.0 reader that unwraps bundles,
    an RFC 1055 SLIP decoder sharing the serial console, and a UDP listener
    on :9000. /straylight/palette/primary/colours (flat RGB floats) drives
    CurrentPalette while in Osc mode; 10 s without a palette clears it and
    turns paint off. Native tests use datagrams from Straylight's encoder.
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2026-10-09 fix(wisp): steadier OSC source per audit
    - Stale threshold 30 s (OscFreshness::kStaleMs): Straylight's UDP feed
    restates a still palette only every 10 s, so 10 s pulsed lamps home.
    - Lamp re-assign, out-of-cadence STATE and ArtNet follow an OSC palette at
    most once a second through a trailing-edge RateGate; the ring stays
    immediate.
    - SLIP decoder drops a frame idle for 200 ms and returns to text, so a cut
    frame cannot leave the console deaf.
    - A blank palette (unbound Straylight role) counts as no palette and holds
    lamps at Off at once.
    - A role change keeps painting until the new role's first palette; the
    dedup keys on the role instead of dropping liveness.
    - Manual with an emp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
2026-10-09 test(wisp): pin the 30 s stale threshold and the empty-SLIP-frame skip
    The restate test now carries arrival jitter and a lost restate, so a 10 s
    threshold fails it; the back-to-back test now feeds END END, so dropping
    the empty-frame skip fails it.
2026-10-09 fix(wisp): STA joins only in Osc on channel 6 with backoff; re-audit fixes
    Owner request: a stored network that is not there made the wisp rescan all
    channels every ~5 s, pulling the radio off the mesh until lamps aged out.
    The STA join now runs only while the source is Osc, names the mesh channel
    so a scan never leaves it, and retries on a RetryBackoff (10 s doubling to
    5 min) with the core auto-reconnect off. Off/Manual drop any association;
    creds stay in NVS.
    - Any parsed /straylight/ packet keeps a held palette live: over UDP the
    palette is the datagram dropped from each restate burst.
    - ArtNet stays released while the current palette is empty, and the ring
    renders before every ArtN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
2026-10-09 fix(wisp): event-judged STA join that scans channel 6 first; audit fixes
    WiFi.status() is latched from the last event, so a join judged by it read
    the previous attempt's NO_SSID_AVAIL and never joined again. The join
    policy is now StaJoin, a pure, natively tested state machine fed WiFi
    events (disconnects the wisp did not cause, GOT_IP) and scan results.
    Each attempt scans channel 6 only for the stored SSID and calls
    WiFi.begin(ssid, pass, 6, bssid) only when it is there; a missing AP is a
    failure on the backoff with no wider scan. A GOT_IP from the core's own
    retry is adopted. Drops re-pin the radio only when it left channel 6.
    - A packet with this role's palette that fails to parse no lon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
2026-10-09 refactor(wisp): drop StaJoin's remaining unobservable backoff stops
    Halted, like Idle, never consults the backoff, and every exit from either
    to Waiting goes through arm(), which resets it.
2026-10-09 fix(wisp): ignore WiFi events from before the last drop; audit LOWs
    - dropJoin() marks every event so far as applied, so a GOT_IP for a link
    already dropped is never adopted; events apply in sequence order and one
    older than the newest applied is skipped. While linked, the netif
    CONNECTED bit backs up the disconnect event.
    - The channel guard reads the channel the adopted GOT_IP carried instead of
    a pending slot that clearMismatch() could zero.
    - Tests: restart() drops from Waiting and Halted; onConnected() drops while
    Halted.
    - Comment, debug-instruments and networking.md follow.
    HELLO flags bit 2 (WISP_HELLO_FLAG_SOURCE_LIVE, was AURORA_CONNECTED) is a
    rename of a bit no receive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
2026-10-09 feat(wisp): wired Ethernet over a W5500 on SPI; STA joins only in Osc without it
    The wisp probes for a W5500 once at boot (ETH.begin, DHCP). With none
    fitted the probe fails fast, the SPI bus is freed and the pins return to
    reset state. With Ethernet up (link plus lease) staWanted() keeps the STA
    off the radio; IPv4 multicast is blocked at the chip. eth:show on the
    console. Pins are WISP_ETH_* build flags.
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2026-10-09 fix(wisp): strip-pin comment named GPIO 0 as the BOOT strap; the C6's is GPIO 9
2026-10-09 fix(wisp): Ethernet audit round
    DHCP hostname wisp-<name> (sanitized, natively tested); log a failed
    spi_bus_free; formatIp reads localIP once and treats 0.0.0.0 as down. The
    app hides a held channel mismatch while on Ethernet. Docs: the binding
    status ceiling is the lamp's 512 B CHAR_WISP_STATUS read, the Ethernet-down
    edge clears a channel-guard halt, broadcast is not filtered, IP forwarding,
    the softAP subnet, and the expected error lines on a module-less boot.
2026-10-09 feat(wisp): split settings into an on-demand wispConfig broadcast
    wispConfig carries ledType, px, brightness, drift, shuffleSeed and opSeq,
    every field always present. It goes out at boot, on pollConfig (a new
    read-only plaintext wispOp, coalesced), and after any status emit that
    finds it changed, re-sent through that change's burst. ConfigCadence keeps
    a config and a status at least 250 ms apart, since a lamp holds one inbound
    control op per loop pass.
    wispStatus keeps the config fields as a lowest-priority copy for lamps that
    predate wispConfig; live fields now outrank all of them. Additive JSON tag
    on MSG_CONTROL_OP: old lamps relay it unchanged and drop it at apply, so no
    protocol bump.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
2026-10-09 fix(wisp): drift rides the status copy in Off; drop relays of own broadcasts
    The app's drift form shows in every source mode, and an Off status without
    drift read as the parser defaults, which a nudge then saved. The copy now
    carries drift in every mode (Off worst case 421 B, under 576).
    A lamp's relay of the wisp's own wispStatus / wispConfig landed in the
    single op slot and could overwrite a pending app op, whose unicast resends
    the dedup then swallowed. controlOpForWisp now drops frames this wisp sent.
2026-10-09 fix(lamp): wisp broadcasts bypass the inbound op slot; notify only on a changed config
    The WiFi-task control-op handler peeks the payload's leading "char" and posts
    wispStatus and wispConfig straight to their own slots, so a wisp broadcast
    never overwrites another op waiting in the single inbound slot.
    cacheWispConfig keeps an identical re-send from moving configLastSeenMs, so
    the app re-reads the section once per real change, not once per burst copy.
    The wispstatus section assigns into the connection's snapshot in place.
2026-10-09 fix: pin char-first serialization, hold released sliders for the echo, drop malformed wispConfig
    The lamp routes wisp broadcasts by their leading bytes, so test_status_json
    now pins that both builders write "char" first.
    The drift and space-brightness sliders hold the released value until the wisp
    echoes it or 2.5 s pass: writes are debounced, so a status from mid-drag can
    arrive after release carrying an intermediate value.
    drainWispConfig drops a payload that does not parse as a JSON object before
    it can replace the cache or move configLastSeenMs. Comments in
    lamp_remote_op.cpp now say which wisp payloads still reach it, and
    networking.md records the empty-notify residual.
    Co-Authored-B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
2026-10-10 fix(lamp): config saves serialize into one guarded buffer and retry when the heap is short
    persistConfig built the whole config into an Arduino String; a failed reserve on
    a fragmented heap left a null buffer that putString dereferenced, and an
    overflowed JsonDocument would have saved a truncated config. The save now gates
    the document build on the largest free block, refuses an overflowed document,
    serializes once into an exactly-sized nothrow buffer, and on a short heap logs,
    keeps the in-memory state and retries every 5 s from the loop. The commit drain
    hashes and writes that same buffer instead of serializing the config twice.
    Stored bytes are unchanged.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
2026-10-10 fix(lamp): bound transient cascades and drop the per-frame HMAC allocations
    Each distinct cascade sender added a heap Expression pair with no count limit;
    transients are now capped at 8 in flight, reserved at begin(), and the target
    list is a fixed array. The command/event HMAC ran mbedtls_md_hmac, which callocs
    two contexts per call, on the WiFi task for every frame overheard; it now
    computes RFC 2104 over stack-held SHA-256 contexts. Tag bytes are unchanged
    (RFC 4231 known-answer test added). The BLE section caches warm only while a
    client holds the link, so a mesh cascade no longer rebuilds the expressions
    section with no reader.
2026-10-10 fix(lamp): hold mesh invocations to the expression caps
    A MSG_COMMAND or MSG_EVENT invocation accepted as many colours and parameter
    keys as its frame held (about 180 colours in a command), each copied into the
    transient it starts and into the delayed-trigger queue. parseInvocation now
    keeps at most 8 colours and 16 parameters; the caps move to config_types so the
    config codec and the invocation parser share them.
2026-10-10 fix(lamp): cut the crowd-driven allocations on the scan, cascade and notify paths
    - The BLE scan callback built a 17-char address string (past SSO) per lamp
    advertisement on the host task only for the roster to parse it back; it now
    passes the six address bytes.
    - A cascade fan-out built a JsonDocument and a string per peer, up to 50 per
    fire; it now builds the document once and reuses one string, rewriting only
    delayMs (byte-identical payloads, tested).
    - A delayed trigger was deep-copied twice into the queue; it now copies once.
    - The compositor reserves slots for transients and live upserts at boot, so
    cascades never regrow its behavior list.
    - notifyStateChange built its payloa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
2026-10-10 perf(lamp): store expression parameters inline, one config copy per expression
    Expression parameters were a std::map<std::string, uint32_t>: a heap node per
    parameter (and the key too past 15 characters), copied whole into every
    expression-manager entry, each transient and each invocation. ExpressionParams
    holds one optional uint32 per kExpressionParamKeys slot (88 bytes, a presence
    mask plus values), copies without allocating, and iterates in key-index order,
    which is the byte-wise order the map used, so every wire stays identical.
    Unknown keys drop at parse as before.
    The manager entry no longer copies the whole ExpressionConfig (type, colours,
    intervals, parameters); it keeps the type an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
2026-10-10 fix(lamp): create the console's UART write lock at boot
    The UART VFS driver creates its write lock (a FreeRTOS mutex) on the first
    write to stdout, and newlib aborts when that allocation fails. Every lamp log
    goes through Serial, so the first stdout write was an IDF driver's error line
    (the WiFi/coex esp_timer task, core 0) on an already starved heap: abort in
    lock_init_generic. setup() now writes one newline to stdout while the heap is
    whole.
2026-10-10 fix(lamp): config records load one by one, survive a reset mid-save, and sections never cache truncated JSON
    The bench read "expressions=0" after a crash as data loss; it was not. That
    boot line counted only expressions inside the cfg JSON, which no longer holds
    them once records exist; the records loaded and every saved type kept firing
    after each reboot. The same run's expr.get output was a truncated section: the
    cache built it in an Arduino String that silently stops appending on a
    fragmented heap, and cached the cut-off JSON as valid (also what the app reads).
    - The boot log reports how many expressions loaded and from where.
    - A record that fails to read drops only itself, logged; a (t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
2026-10-10 docs: save ordering and reset safety, expression runtime footprint, the console lock
2026-10-10 fix(lamp): bound the cascade fan-out burst and gate transients per target
    A test_expression (or any cascade) fanned out to every mesh peer in one pass:
    50 frames queued at once, each holding a WiFi TX buffer until it aired, and the
    driver ran out (esp_now_send 0x3067, ESP_ERR_ESPNOW_NO_MEM) while the heap's
    minimum fell to about 1 KB. A cascade now reaches the 8 closest peers. A remote
    invocation starts its transients only when the largest free block holds 2 KB
    per target plus the headroom, so a transient that starts can finish
    allocating.
2026-10-10 fix(lamp): config saves and the expressions section need no large free block; caches free without a client
    A churn round left about 5 KB never returned: the BLE section caches, the
    expressions section (about 4 KB at the worst case) above all, stayed resident
    after a serial expr.get/cfg.get with no client to read them. Rebuilding that
    section built a whole JsonDocument first, a burst of small blocks on a
    fragmented heap, then failed ("expressions section OOM; serving stale").
    Config saves needed 8 KB contiguous and sat deferred for minutes at a steady
    8.7 KB largest block.
    - JsonWriter serializes compact JSON straight into a fixed buffer, or only
    measures it, byte-identical to ArduinoJson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
2026-10-10 fix(lamp): cascade fan-out reaches every peer in batches of 8
    Replaces the closest-8 cap. CascadeScheduler holds the peers (every mesh peer,
    closest first) and the one serialized invocation in fixed storage, about 1.1 KB
    of .bss, and the loop sends the next 8 frames every 50 ms, so the WiFi driver
    never holds more than a batch of TX buffers. Each frame's delayMs is rewritten
    in place to keep the peer's intended fire time ((i + 1) x stagger capped at
    kMaxDelayMs from the original fire, less the drain's elapsed time, never
    negative), so the frames match serializeInvocation byte for byte. A new
    cascade replaces the remainder of one still draining (logged); an OTA start
    stops the drain. Tests: d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
2026-10-10 fix(lamp): bound ESP-NOW frames in the driver; cascades queue, pace past their resends
    Round 6's batches of 8 every 50 ms queued frames faster than the driver aired
    them under coex and relay load: 28 esp_now_send ESP_ERR_ESPNOW_NO_MEM failures
    during the first two cascades, where round 5 (8 peers) had none. Minutes later
    the TX path wedged with its dynamic TX buffers held (about 8 KB) and every
    broadcast after it failed the same way.
    - TxCredit bounds the frames handed to the driver and not yet reported by the
    send callback (6). Every ESP-NOW submit takes a credit; the callback returns
    it; a submit the driver refuses returns it at once; a count no credit moves
    for 2 s is presumed lost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
2026-10-10 fix(lamp): reserve transient slots for the lamp's own triggers; test the crowd guards
    admitTransient (expressions/transient_admission.hpp) is the admission gate as a
    pure function: four slots, at most two for a peer's cascades and echoes, so
    the Test button and greetings always have room, and an invocation starts only
    when the heap can hold all its instances. A dropped transient logs on every
    build, at most every 5 s. The params lookup and the upsert mirror move into
    config_codec (findExpressionParams, mirrorUpsert) with native tests.
    invocationToJson, left without a caller by the cascade scheduler, is removed.
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2026-10-10 fix(lamp): size the cfg buffer for fully escaped fields; count NimBLE bonds in the NVS budget
    JsonWriter writes a '"' or '\\' as two bytes, so free-text fields at their
    caps made of either produced about 2.1 KB of cfg JSON, over the 2 KB buffer:
    every save would have failed TooLarge. The buffer is now 2176 bytes, above the
    measured fully escaped worst case (2106). To keep that inside the NVS budget:
    - the parameter cap drops from 16 to 12 (every type carries at most 11 keys,
    now guarded by test_builtin_descriptors), so an expression record is 6 NVS
    entries instead of 7;
    - a home-mode disabled type must be a type id (lowercase, digits, '_'), so it
    never escapes.
    The budget's system allo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
